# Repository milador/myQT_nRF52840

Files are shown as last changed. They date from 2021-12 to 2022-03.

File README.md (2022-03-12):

# myQT_nRF52840

myQT nRF52840 is a development board based on Nordic nRF52840 Bluetooth module in Seeeduino XIAO/QT py form factor.

## myQT nRF52840 Arduino IDE Setup

Please visit [milador-arduino](https://github.com/milador/milador-arduino/blob/main/boards/README.md) github page to find out about installation process.

## myQT nRF52840 Pinout

<p align="center">
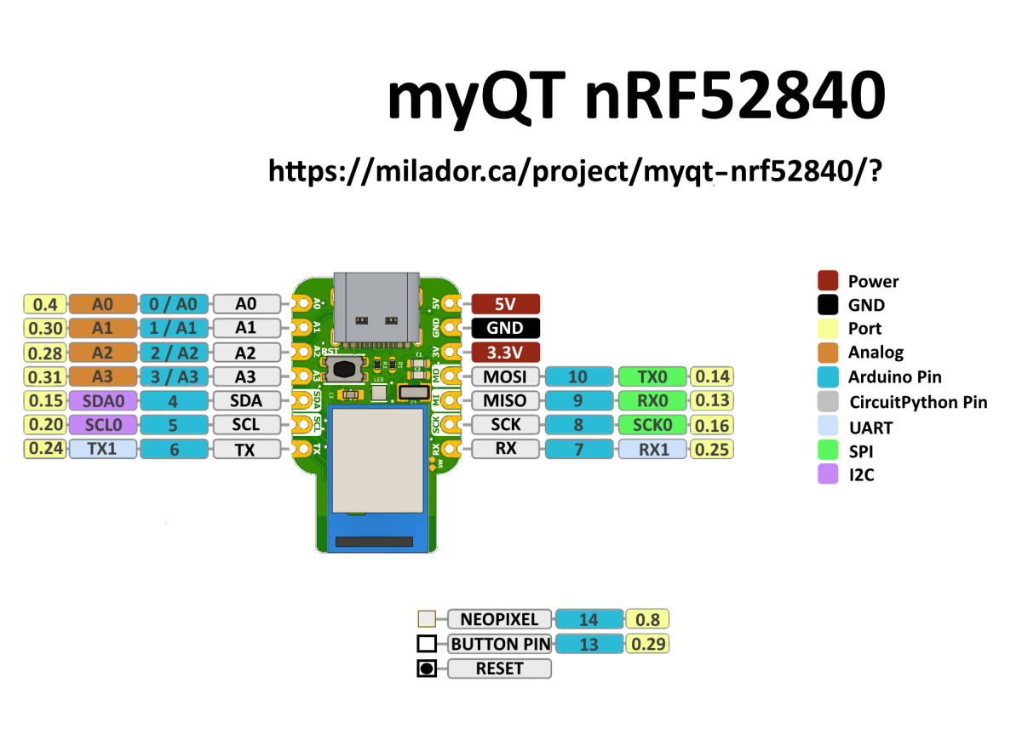
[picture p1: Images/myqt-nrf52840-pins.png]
myQT nRF52840 Pinout

</p>

## myQT nRF52840 PCB Design 

<p align="center">
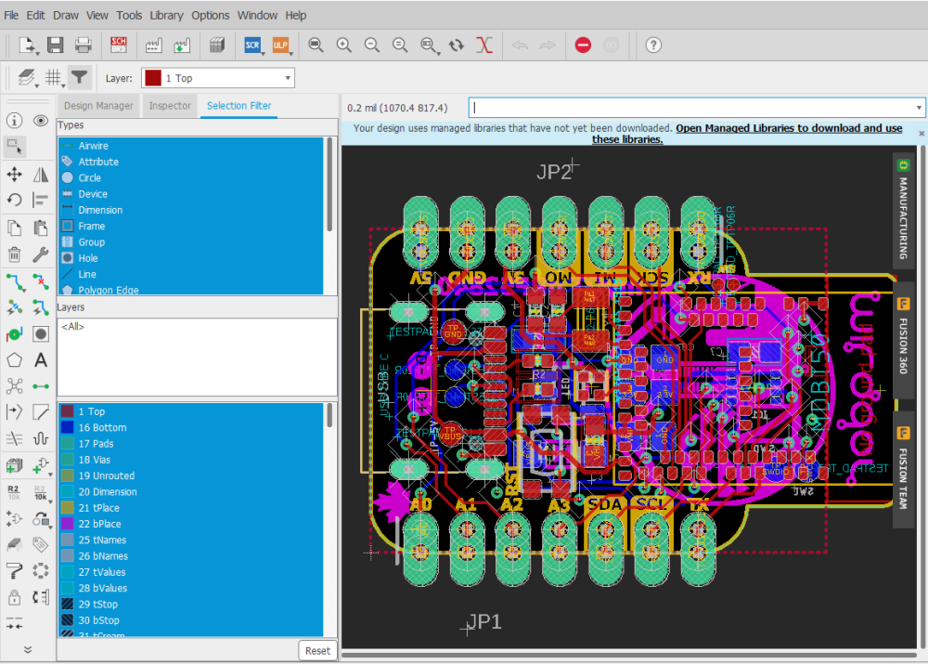
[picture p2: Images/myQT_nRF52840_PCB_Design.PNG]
myQT nRF52840 PCB Design

</p>

## myQT nRF52840 3D Model

<p align="center">
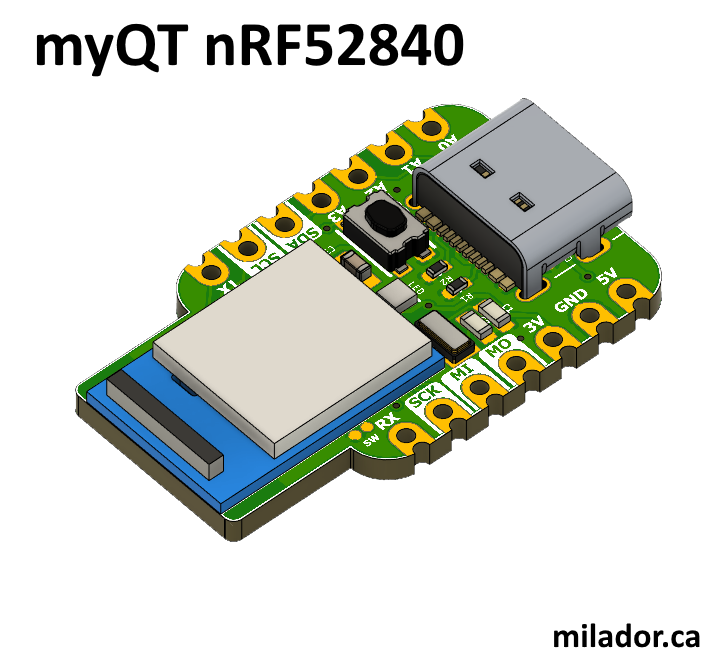
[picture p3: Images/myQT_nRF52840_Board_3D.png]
myQT nRF52840 3D Model

</p>

## License

Designed by milador based on Adafruit QT py design.

Creative Commons Attribution/Share-Alike, all text above must be included in any redistribution. Please read license.txt for additional details.

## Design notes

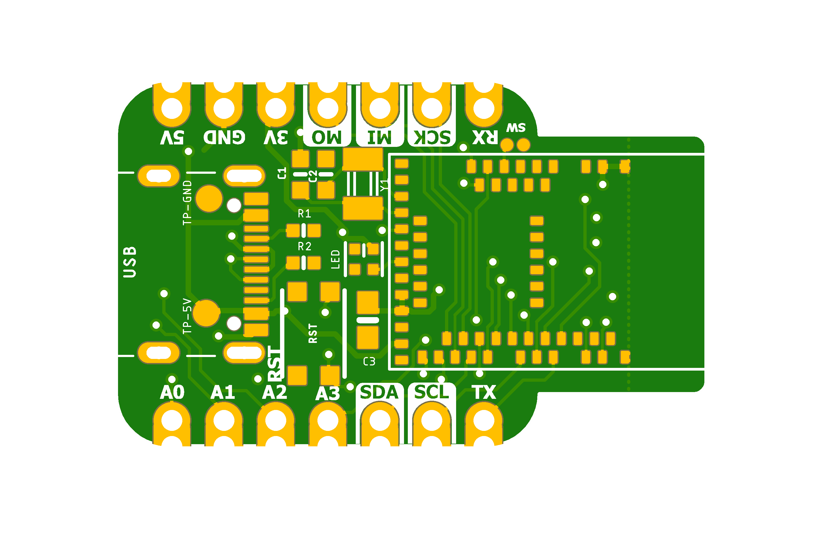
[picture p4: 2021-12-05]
PCB/myQT_nRF52840_Board.png

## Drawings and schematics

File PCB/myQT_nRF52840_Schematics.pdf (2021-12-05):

# Visuals/Labels

A

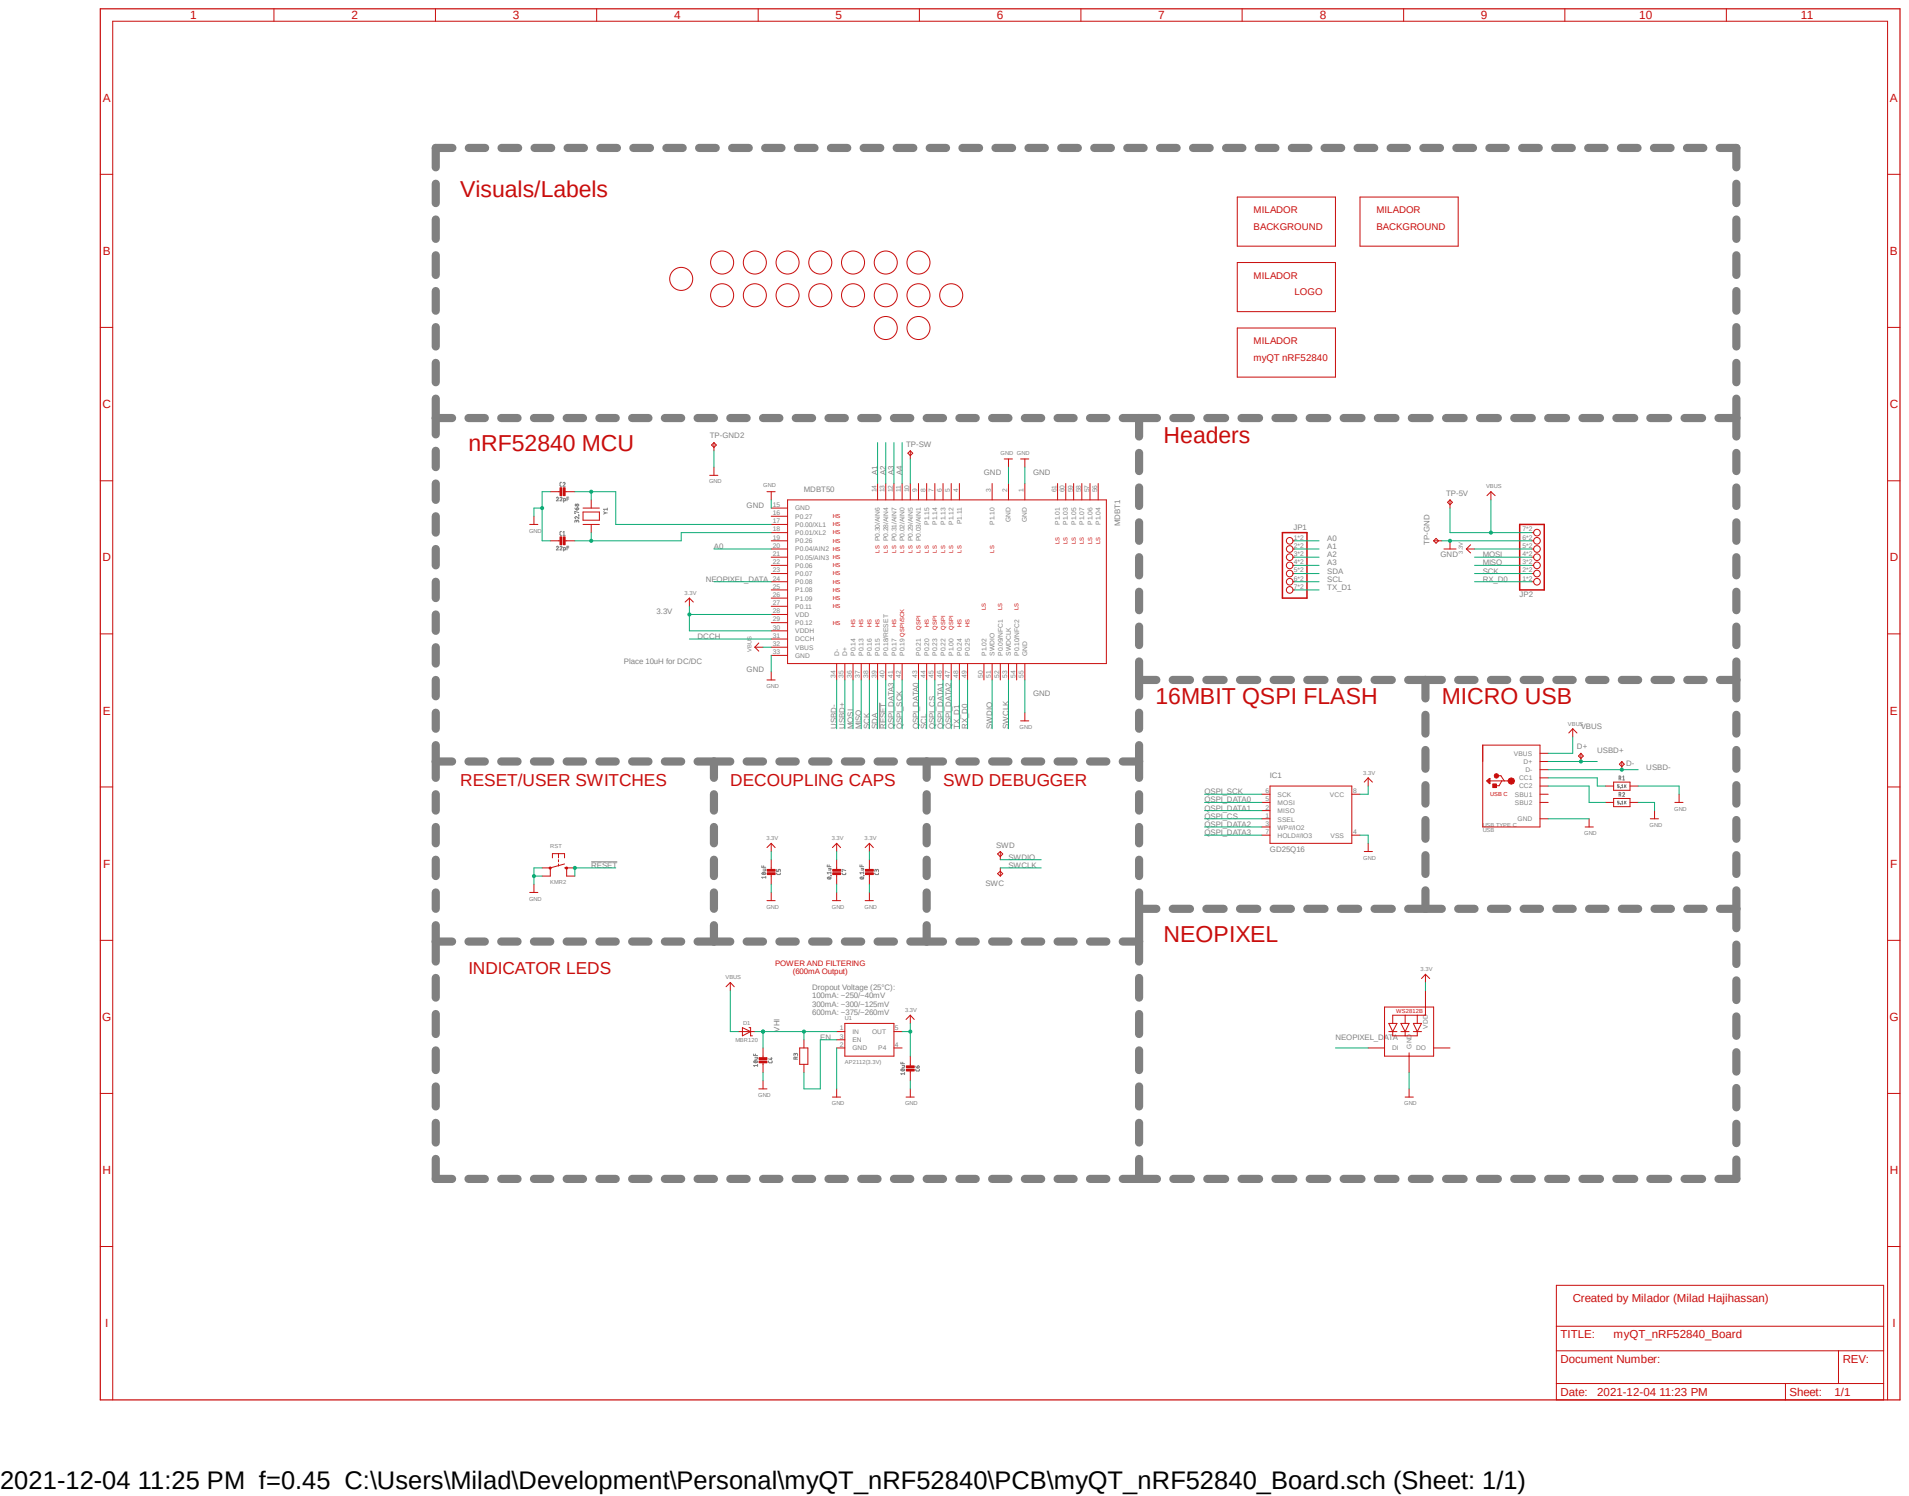
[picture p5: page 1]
Dropout Voltage (25°C): 100mA: ~250/~40mV; Place 10uH for DC/DC; VBUS; GND; KMR2 GND; VBUSMBR120; MDBT50; GND GND; GND GND GND; 3.3V GND; GND ³.3V; VBUS USB TYPE C; RST; GND 2; OUT; D⁺ 35 D⁻ 34 DCCH 31; 1 GND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

MILADOR
BACKGROUND MILADOR myQT nRF52840 MILADOR

2 GND 15 GND 33 GND 55 P0.00/XL1 17 P0.01/XL2 18 P0.02/AIN0 11 P0.03/AIN1

8 SWDCLK 53 SWDIO 51 VBUS 32 VDD 28 VDDH 30 MDBT1 HOLD#/IO3 7 MISO 2 MOSI 5 SCK 6 SSEL 1 VCC 8 VSS 4 WP#/IO2 3

SWDIO SWCLK SWCLK

Created by Milador (Milad Hajihassan)

2021-12-04 11:25 PM f=0.45 C:\Users\Milad\Development\Personal\myQT_nRF52840\PCB\myQT_nRF52840_Board.sch (Sheet: 1/1)

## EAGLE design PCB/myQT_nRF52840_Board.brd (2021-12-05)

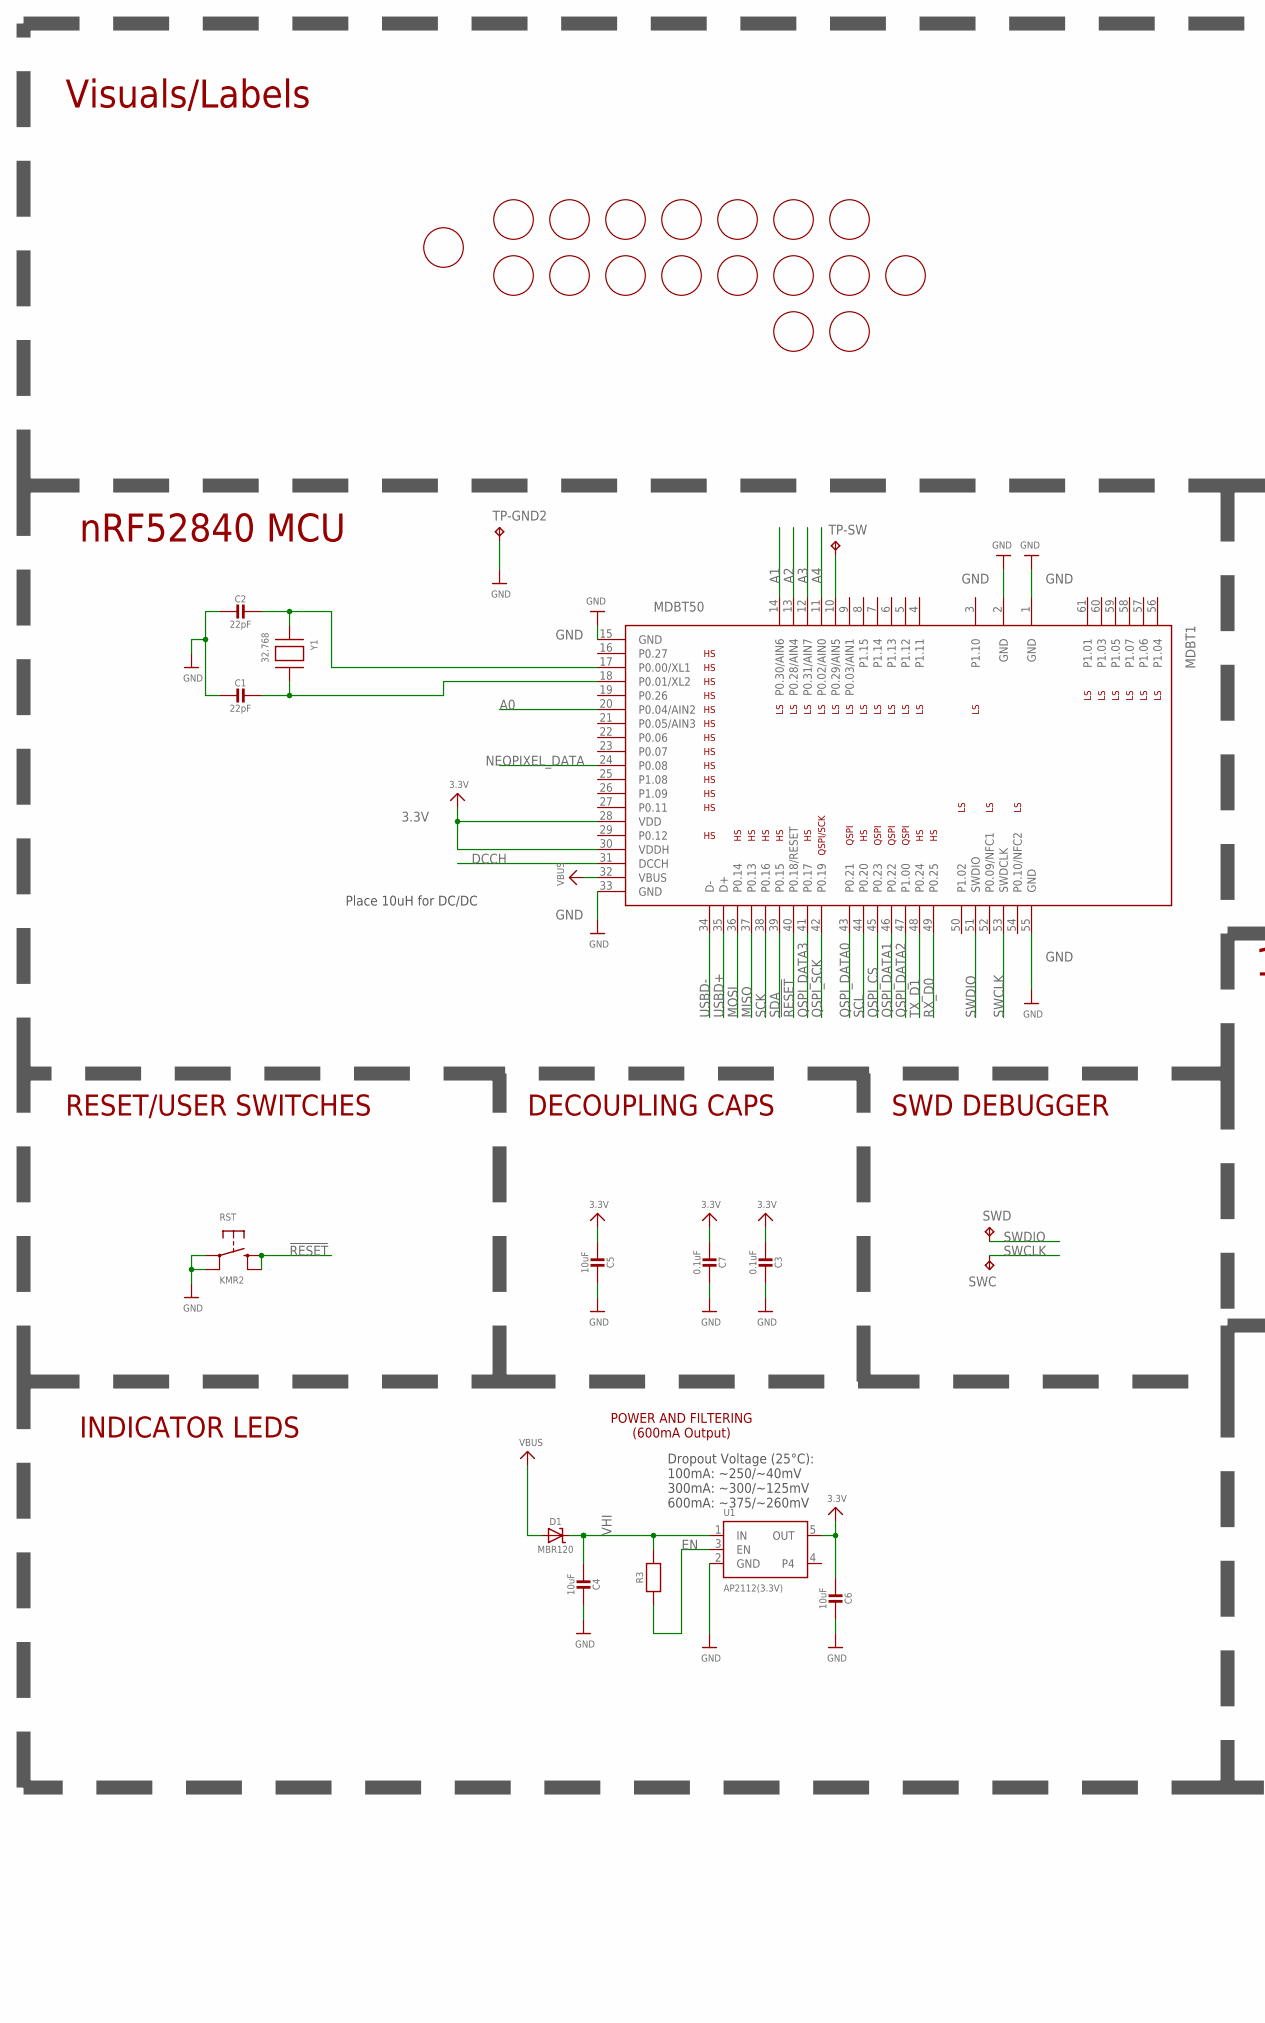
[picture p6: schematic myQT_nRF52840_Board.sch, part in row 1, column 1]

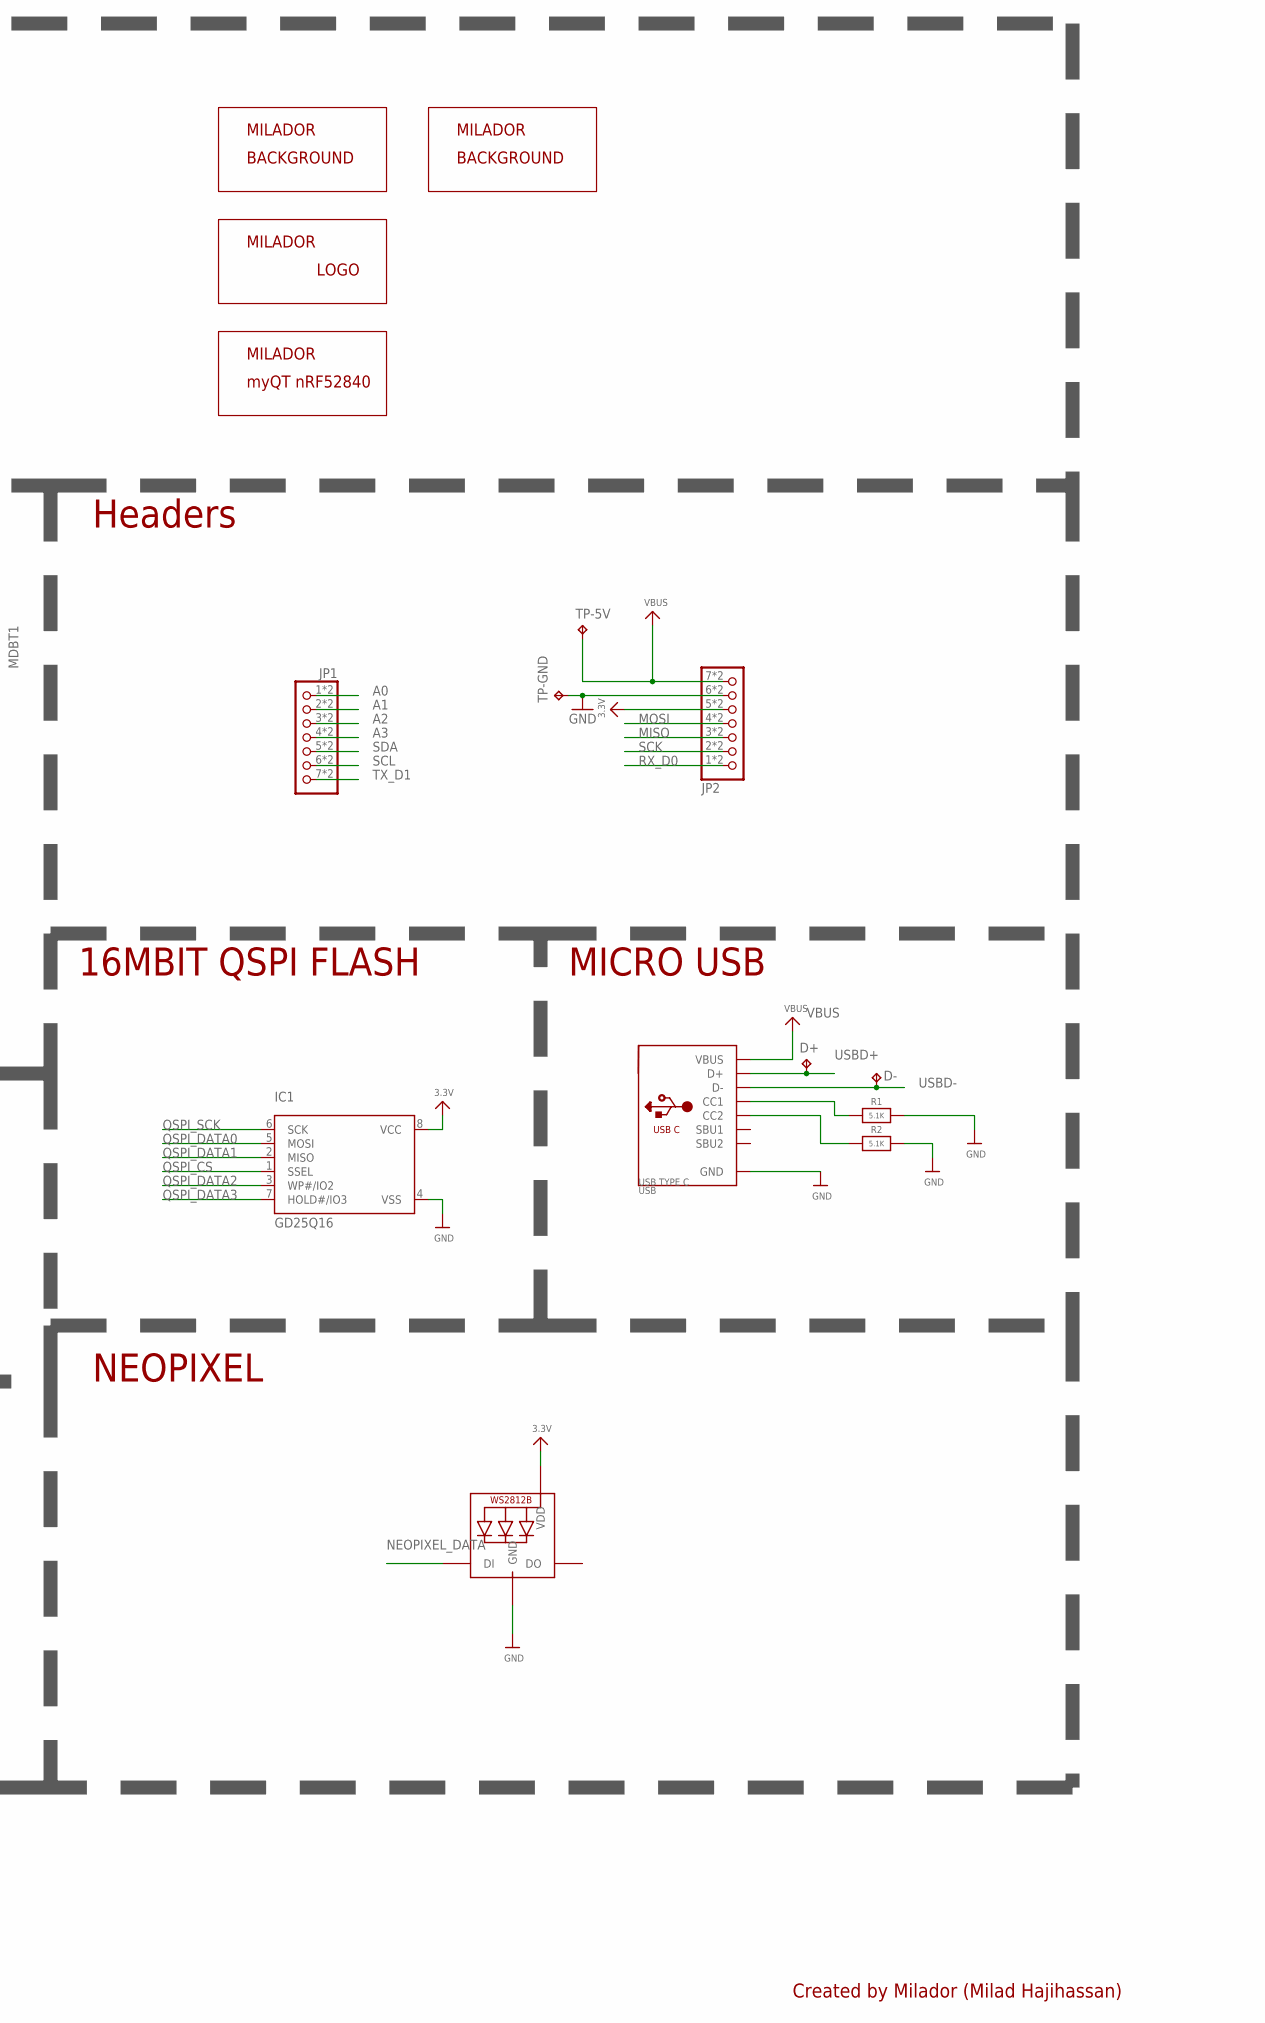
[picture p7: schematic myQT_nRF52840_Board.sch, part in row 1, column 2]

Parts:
C1, C2: 22pF; 0603-MP
C3, C7: 0.1uF; 0603-NO
C4, C5, C6: 10uF; 0805-NO
D1: MBR120; SOD-123
D+: TESTPAD_TPTP10R; TESTPAD_TP10R
D-: TESTPAD_TPTP10R; TESTPAD_TP10R
IC1: GD25Q16; USON8
JP1, JP2: HEADER-1X7_CASTEL; 1X07_CASTEL
LED: WS2812B_SK6805_1515; SK6805_1515
MDBT1: MDBT50
R1, R2: 5.1K; 0402-NO
R3: 10K; 0603-NO
RST: KMR2; BTN_KMR2_4.6X2.8
SWC: TESTPAD_TPTP13R; TESTPAD_TP13R
SWD: TESTPAD_TPTP13R; TESTPAD_TP13R
TP-5V: TESTPAD_TPB1,27; TESTPAD_B1,27
TP-GND: TESTPAD_TPB1,27; TESTPAD_B1,27
TP-GND2: TESTPAD_TPTP06R; TESTPAD_TP06R
TP-SW: TESTPAD_TPTP06R; TESTPAD_TP06R
U1: AP2112(3.3V); SOT23-5
U$6: MILADOR-PIN-NAME-A0; PIN-A0
U$7: MILADOR-PIN-NAME-5V; PIN-5V
U$10: MILADOR-PIN-NAME-GND; PIN-GND
U$12: MILADOR-PIN-NAME-3V; PIN-3V
U$14: MILADOR-PIN-NAME-MO2; PIN-MO2
U$18: MILADOR-PIN-NAME-MI2; PIN-MI2
U$20: MILADOR-PIN-NAME-SCK2; PIN-SCK2
U$24: MILADOR-PIN-NAME-RX; PIN-RX
U$25: MILADOR-PIN-NAME-A1; PIN-A1
U$26: MILADOR-PIN-NAME-A2; PIN-A2
U$27: MILADOR-PIN-NAME-A3; PIN-A3
U$28: MILADOR-PIN-NAME-TX; PIN-TX
U$29: MILADOR-PIN-NAME-SDA2; PIN-SDA2
U$33: MILADOR-PIN-NAME-SCL2; PIN-SCL2
U$36: MILADOR-PIN-NAME-RST; PIN-RST
U$37: MILADOR-BACKGROUND-VANCOUVER; MILADOR_BG_VAN
U$38: MILADOR-DEVICE-; MILADOR_MYQT_NRF52840
U$39: MILADOR-LOGO-; MILADOR_LOGO1
U$40: MILADOR-BACKGROUND-CANADA_SM; MILADOR_BG_CAN_SM
U$41: MILADOR-PIN-NAME-D+; PIN-D+
U$43: MILADOR-PIN-NAME-D-; PIN-D-
U$44: MILADOR-PIN-NAME-SW; PIN-SW
USB: USB TYPE C; USB_C_CUSB31-CFM2AX-01-X
Y1: 32.768; ADAFRUIT2_XTAL3215

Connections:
3.3V: C3.2, C5.2, C6.2, C7.2, IC1.8 (VCC), JP2.5, JP2.5C (5), LED.2 (VDD), MDBT1.28 (VDD), MDBT1.30 (VDDH), U1.5 (OUT)
!RESET: MDBT1.40 (P0.18/RESET), RST.B (S), RST.B' (S1)
A0: JP1.1, JP1.1C (1), MDBT1.20 (P0.04/AIN2)
A1: JP1.2, JP1.2C (2), MDBT1.14 (P0.30/AIN6)
A2: JP1.3, JP1.3C (3), MDBT1.13 (P0.28/AIN4)
A3: JP1.4, JP1.4C (4), MDBT1.12 (P0.31/AIN7)
A4: MDBT1.11 (P0.02/AIN0)
DCCH: MDBT1.31 (DCCH)
EN: R3.1, U1.3 (EN)
GND: C1.2, C2.2, C3.1, C4.1, C5.1, C6.1, C7.1, IC1.4 (VSS), JP2.6, JP2.6C (6), LED.4 (GND), MDBT1.1 (GND), MDBT1.2 (GND), MDBT1.15 (GND), MDBT1.33 (GND), MDBT1.55 (GND), R1.2, R2.2, RST.A, RST.A' (P1), TP-GND.TP, TP-GND2.TP, U1.2 (GND), USB.A1B12 (GND), USB.B1A12 (GND)
MISO: JP2.3, JP2.3C (3), MDBT1.37 (P0.13)
MOSI: JP2.4, JP2.4C (4), MDBT1.36 (P0.14)
unnamed: MDBT1.10 (P0.29/AIN5), TP-SW.TP
unnamed: R1.1, USB.A5 (CC1)
unnamed: R2.1, USB.B5 (CC2)
unnamed: C2.1, MDBT1.17 (P0.00/XL1), Y1.P$1
unnamed: C1.1, MDBT1.18 (P0.01/XL2), Y1.P$2
NEOPIXEL_DATA: LED.1 (DI), MDBT1.24 (P0.08)
QSPI_CS: IC1.1 (SSEL), MDBT1.45 (P0.23)
QSPI_DATA0: IC1.5 (MOSI), MDBT1.43 (P0.21)
QSPI_DATA1: IC1.2 (MISO), MDBT1.46 (P0.22)
QSPI_DATA2: IC1.3 (WP#/IO2), MDBT1.47 (P1.00)
QSPI_DATA3: IC1.7 (HOLD#/IO3), MDBT1.41 (P0.17)
QSPI_SCK: IC1.6 (SCK), MDBT1.42 (P0.19)
RX_D0: JP2.1, JP2.1C (1), MDBT1.49 (P0.25)
SCK: JP2.2, JP2.2C (2), MDBT1.38 (P0.16)
SCL: JP1.6, JP1.6C (6), MDBT1.44 (P0.20)
SDA: JP1.5, JP1.5C (5), MDBT1.39 (P0.15)
SWCLK: MDBT1.53 (SWDCLK), SWC.TP
SWDIO: MDBT1.51 (SWDIO), SWD.TP
TX_D1: JP1.7, JP1.7C (7), MDBT1.48 (P0.24)
USBD+: D+.TP, MDBT1.35 (D+), USB.A6 (D+), USB.B6 (D+)
USBD-: D-.TP, MDBT1.34 (D-), USB.A7 (D-), USB.B7 (D-)
VBUS: D1.A, JP2.7, JP2.7C (7), MDBT1.32 (VBUS), TP-5V.TP, USB.A4B9 (VBUS), USB.B4A9 (VBUS)
VHI: C4.2, D1.C, R3.2, U1.1 (IN)

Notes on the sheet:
POWER AND FILTERING (600mA Output)
Dropout Voltage (25°C): 100mA: ~250/~40mV 300mA: ~300/~125mV 600mA: ~375/~260mV
INDICATOR LEDS
RESET/USER SWITCHES
DECOUPLING CAPS
SWD DEBUGGER
16MBIT QSPI FLASH
MICRO USB
Place 10uH for DC/DC
Created by Milador (Milad Hajihassan)
Headers
nRF52840 MCU
Visuals/Labels
NEOPIXEL

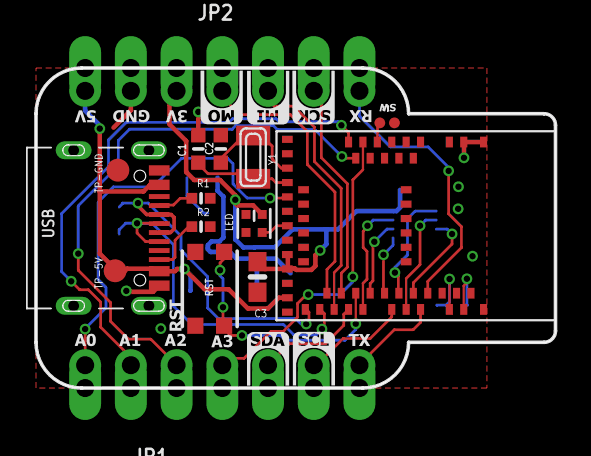
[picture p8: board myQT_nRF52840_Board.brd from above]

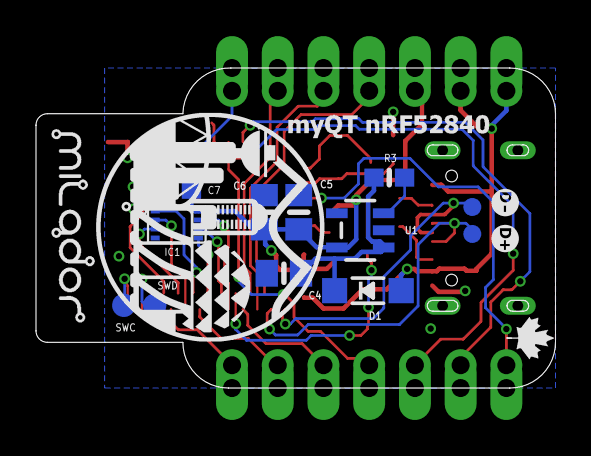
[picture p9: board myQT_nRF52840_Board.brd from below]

Board: 2 copper layers, 28.9 x 17.8 mm, 50 parts (18 on the bottom side), 33 nets.

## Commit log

2021-12-05 Added PCB files
    [myQT_nRF52840_Board.brd, myQT_nRF52840_Board.sch]
2021-12-06 Updated PCB image

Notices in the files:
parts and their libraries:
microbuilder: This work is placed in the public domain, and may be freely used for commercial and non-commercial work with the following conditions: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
